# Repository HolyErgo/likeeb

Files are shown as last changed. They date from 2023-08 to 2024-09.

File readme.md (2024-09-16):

# LIKEeb

### 36-key split wireless keyboard
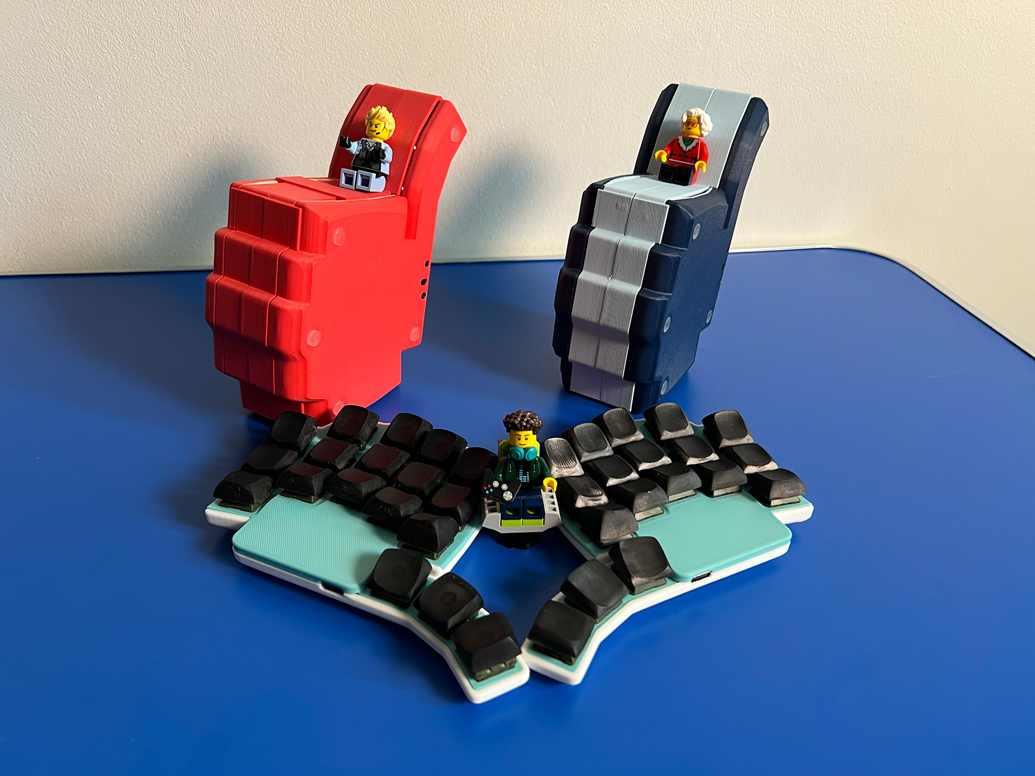
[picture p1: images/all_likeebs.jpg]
Colored likeebs


## Features
- 3x5 key matrix + 3 thumb keys
- highly staggered columns
- rotated pinky and ring columns
- dactyl-like curved columns (not rows)
- Xiao BLE wireless controllers
- hotswap Gateron and Choc V2 switches
- 400mAh battery lasts month or more
- integrated 50-mm magnetic ring
- 2-color case
- magnetic spacer
- no RGB, ergonomics only
- [height-adapted DES-profile keycaps](https://github.com/HolyErgo/DES-MX-low-profile)
- [ZMK firmware](https://github.com/HolyErgo/zmk-likeeb)

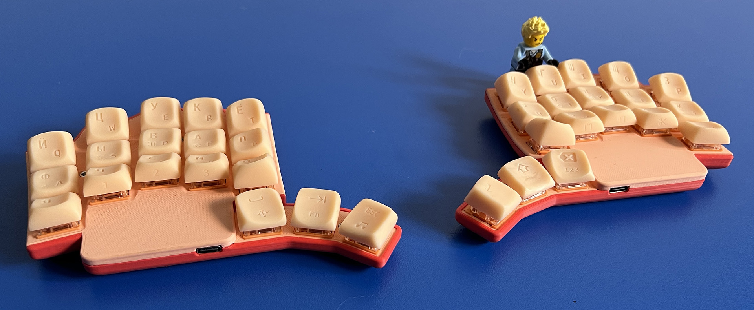
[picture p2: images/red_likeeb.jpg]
Red and biege likeeb

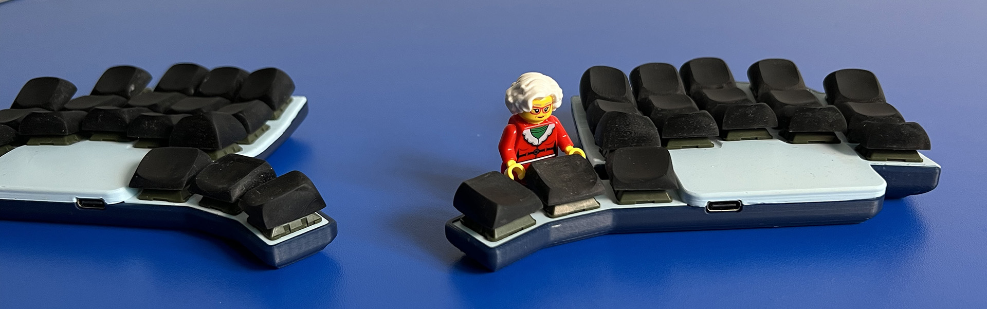
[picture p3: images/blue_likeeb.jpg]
Navy and blue likeeb

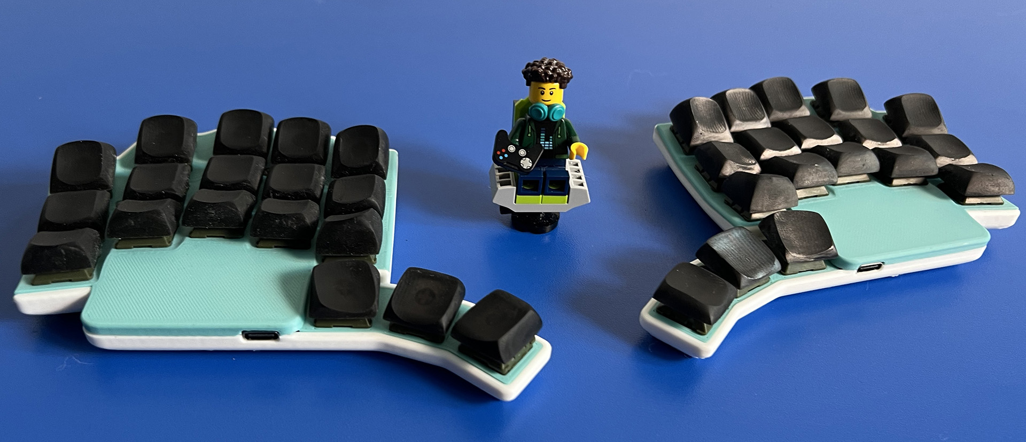
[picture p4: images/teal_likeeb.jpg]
White and teal likeeb


## Comfort and Ergonomics

The curve, stagger, and rotation of the columns provide maximum ergonomics. All keys are easily pressed without moving the base of the hand (for M-L hand size).

Thanks to the low profile, the keyboard is comfortable to use without wrist rests and tents.

Placing the controller under the palm allows for convenient keyboard positioning on either side of a laptop, even on a small café table.

400mAh battery lasts more than a month. I haven’t been able to measure exactly how long, because I always forget when I last charged it :) With the new ZMK firmware using Bluetooth Low Energy protocol, one charge might last 3-4 months.

## Integrated Magnetic Ring

It’s very convenient for designing various mounts. You only need to attach a 0.6mm thick metal ring to the mount. Compared to a magnetic mount, this ring is very thin and much cheaper.

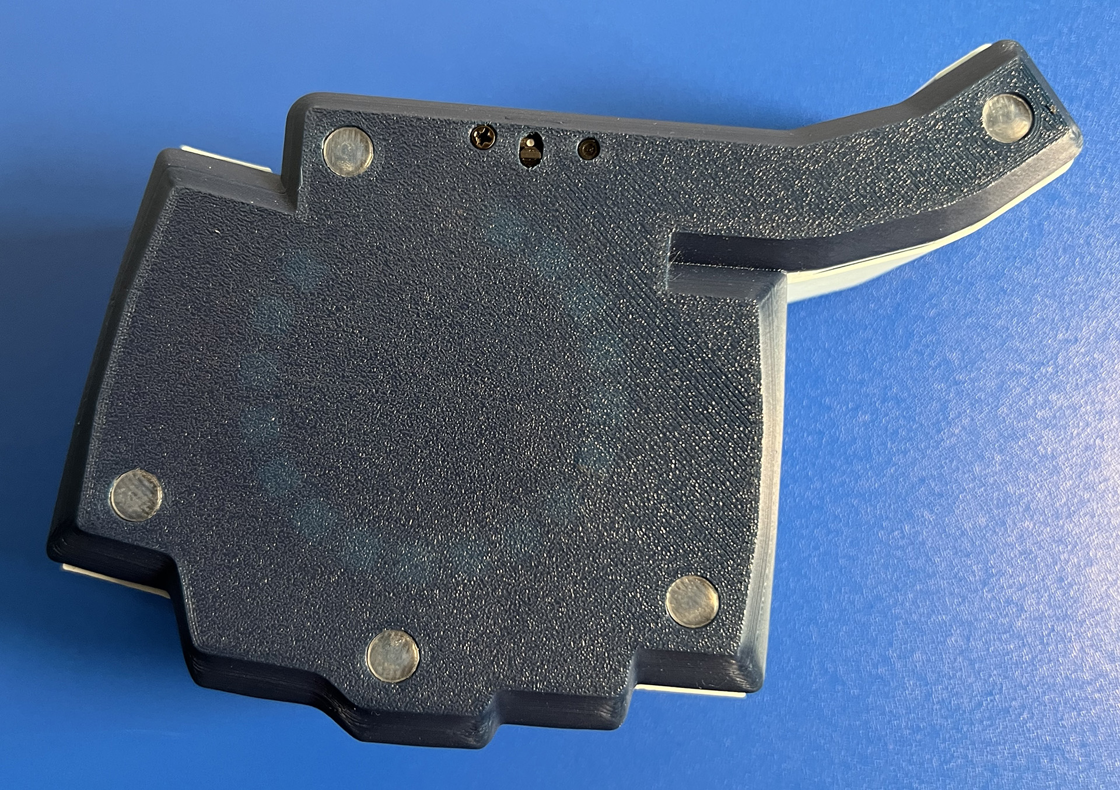
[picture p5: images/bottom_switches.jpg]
Bottom magnet ring and switches


For example, I made a mount for an IKEA garden chair that is only 2mm thick. I simply attached it to the armrest of the chair and created a comfortable workspace: [IKEA chair holder.stl](./case/rev2.0/IKEA%20chair%20holder.stl)

## Convenient Transportation

The magnetic spacer connects two halves of the keyboard and protects the keys from accidental presses. I don’t even turn off the keyboard when I put it in my backpack.

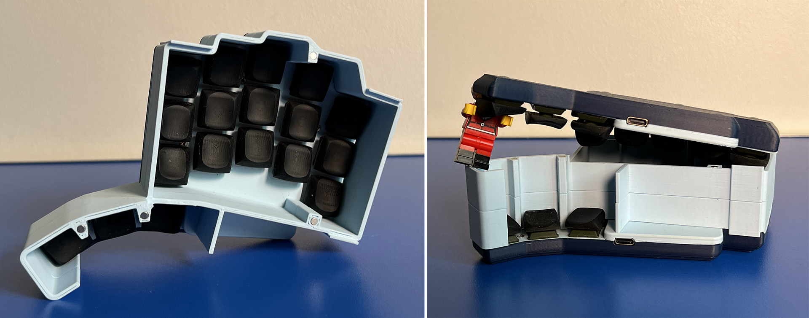
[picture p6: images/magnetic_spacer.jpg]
Magnetic spacer


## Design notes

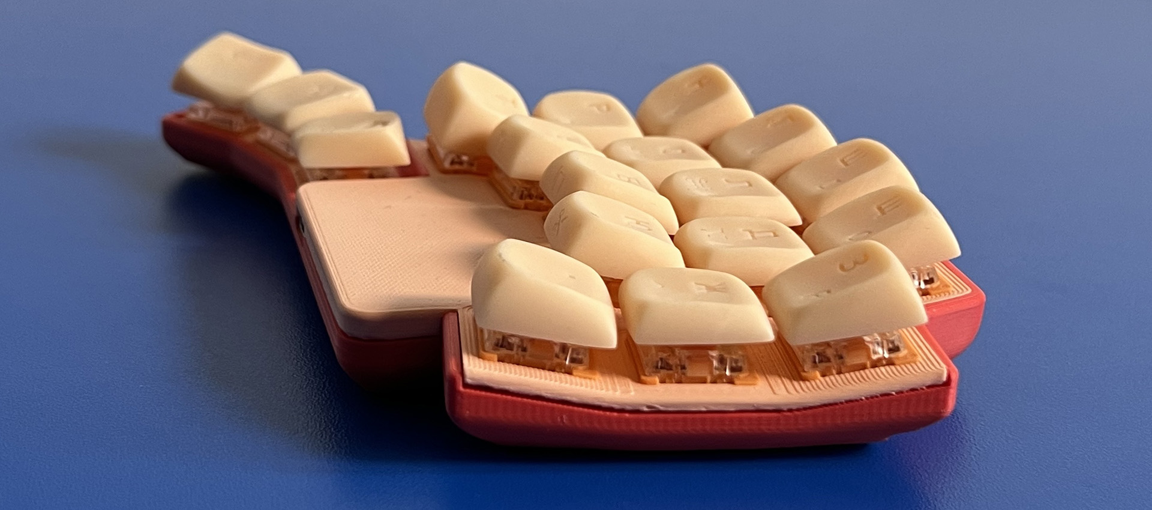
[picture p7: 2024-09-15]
images/curved_columns.jpg

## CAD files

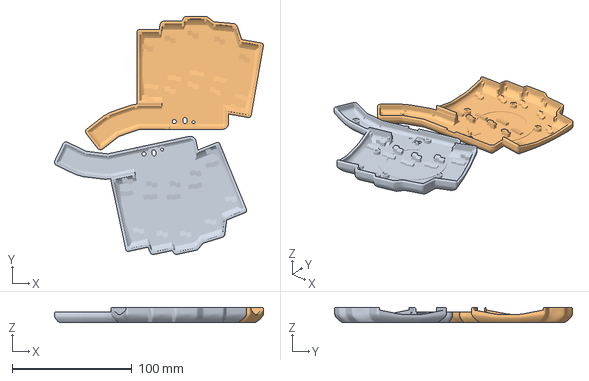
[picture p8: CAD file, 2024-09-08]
case/rev2.0/Bottom.3mf
174.6 x 199.0 x 12.5 mm
bottom l.stl
bottom r.stl

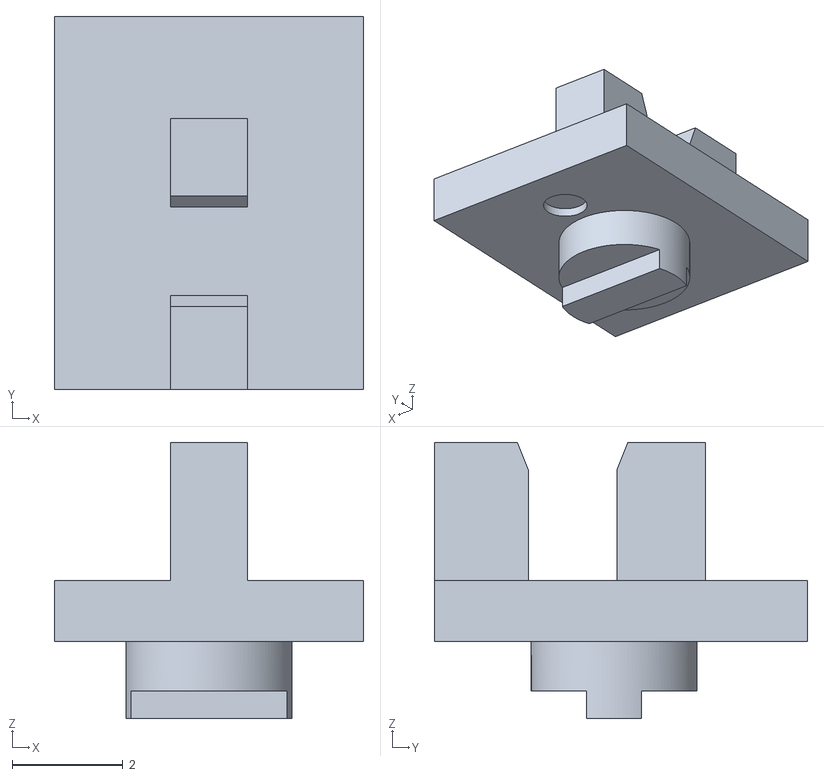
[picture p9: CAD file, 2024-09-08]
case/rev2.0/power stick r.stl
5.60 x 6.75 x 5.00

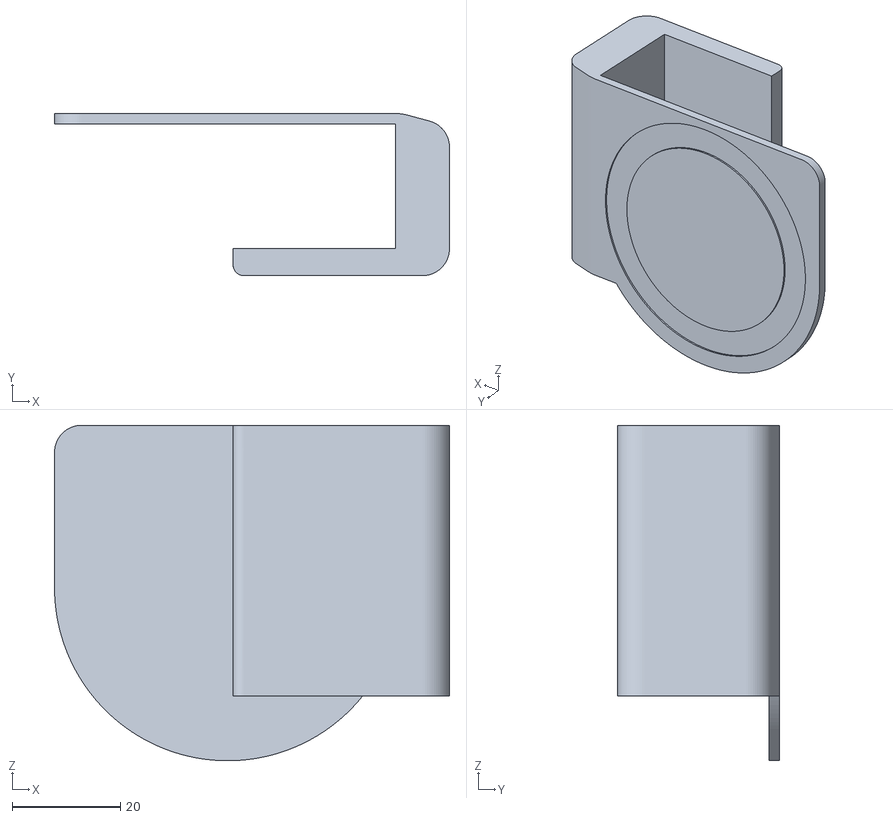
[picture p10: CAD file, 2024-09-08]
case/rev2.0/IKEA chair holder v3.stl
73.0 x 30.0 x 62.0

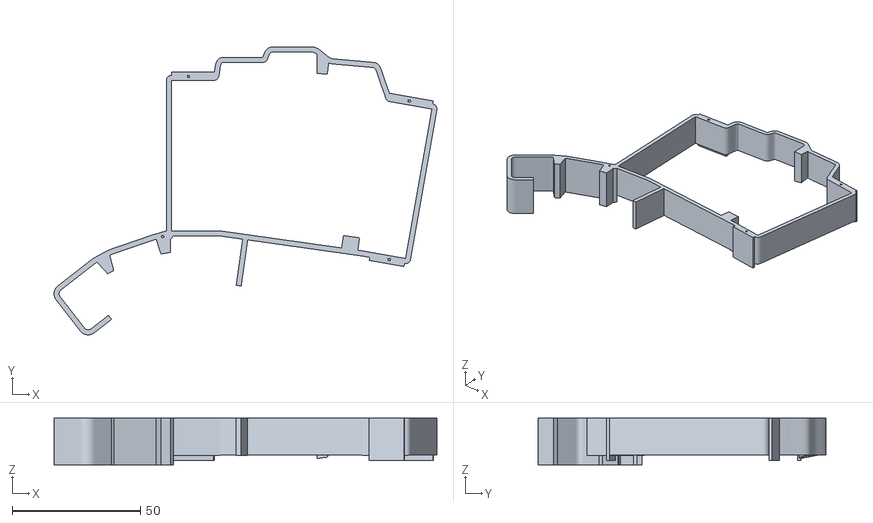
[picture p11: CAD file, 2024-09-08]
case/rev2.0/holder r.stl
149.5 x 112.3 x 18.3

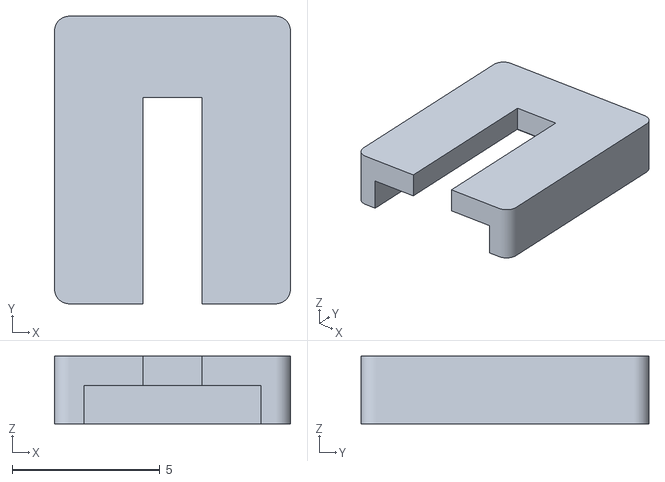
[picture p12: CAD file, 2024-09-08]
case/rev2.0/power holder.stl
8.00 x 9.75 x 2.30

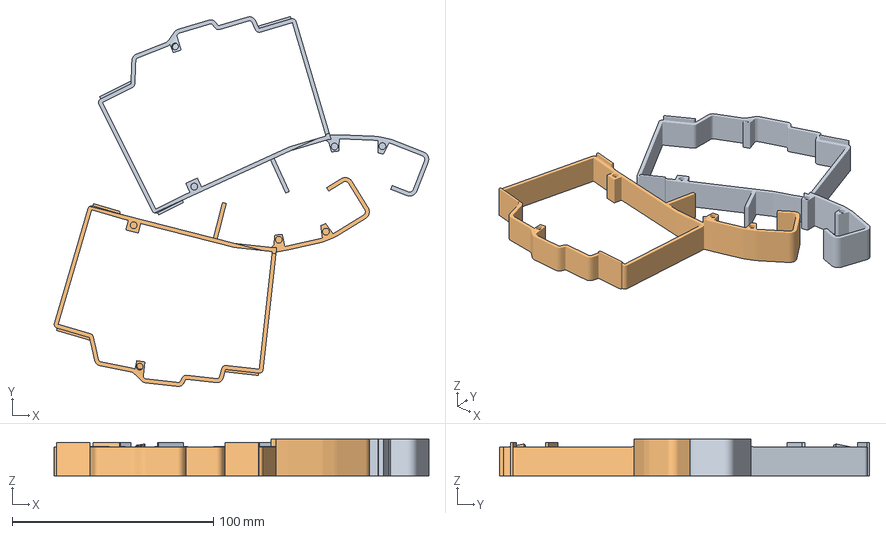
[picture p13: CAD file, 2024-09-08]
case/rev2.0/Holder.3mf
186.1 x 183.8 x 18.3 mm
holder r.stl x 2

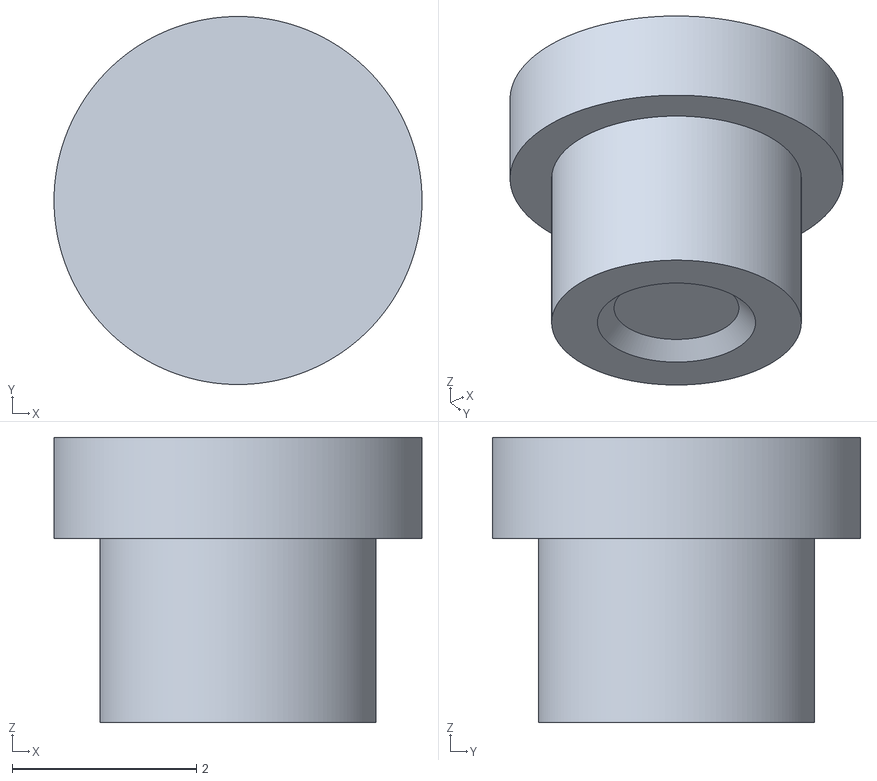
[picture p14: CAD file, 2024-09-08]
case/rev2.0/reset button.stl
4.00 x 4.00 x 3.10

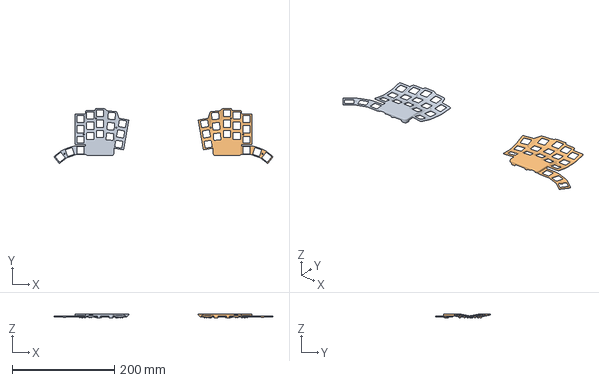
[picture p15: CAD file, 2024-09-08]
case/rev2.0/Top.3mf
428.7 x 107.4 x 7.73 mm
top r.stl
top l.stl

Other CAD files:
case/rev2.0/power stick l.stl

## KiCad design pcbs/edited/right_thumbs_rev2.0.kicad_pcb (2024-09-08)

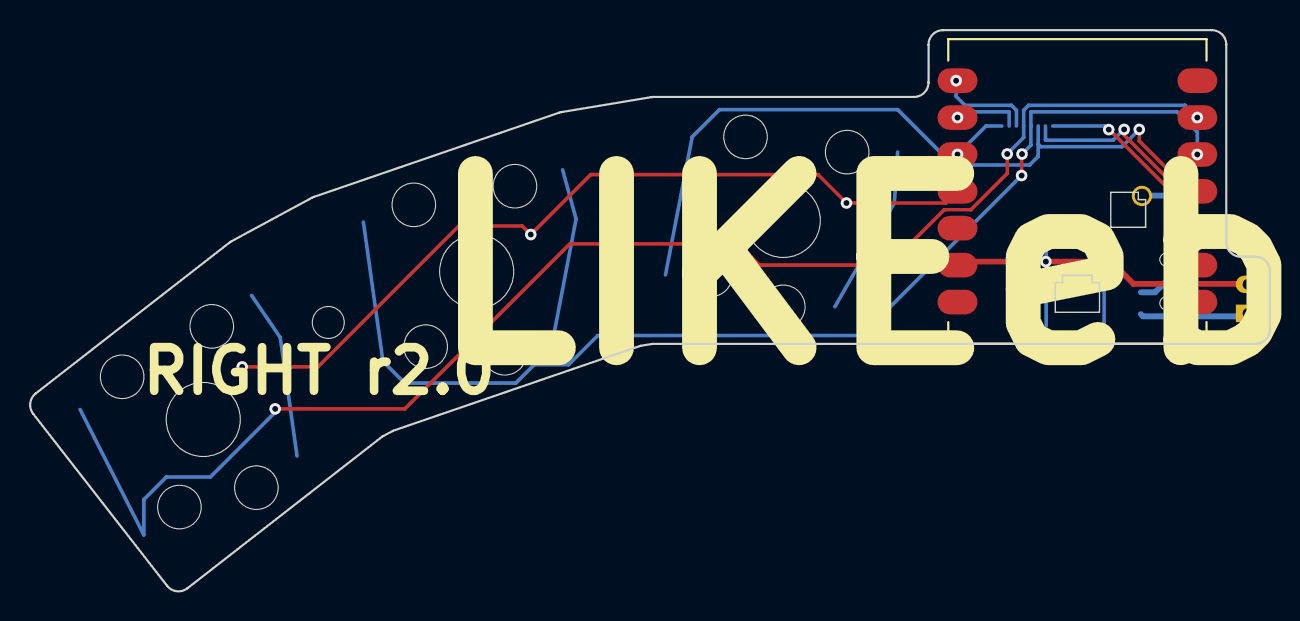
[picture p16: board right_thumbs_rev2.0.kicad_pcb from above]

Board: 2 copper layers, 85.4 x 38.6 mm, 8 parts (1 on the bottom side), 12 nets.

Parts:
B1: SW_TACT_ALPS_SKQGABE010
BAT1: BatteryPad
S1, S2, S3: KS33PG1353
_1: Seeeduino XIAO nRF52840
_2: HKW FPC Socket
_3: MountingHole_2.2mm_M2_Pad_Via

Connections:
C6: S3.1, S3.2, _1.6, _2.4
C7: S2.1, S2.2, _1.5, _2.5
C8: S1.1, S1.2, _1.4, _2.6
C9: _1.3, _2.7
C10: _1.2, _2.8
GND: B1.1, BAT1.2, _1.13
R1: _1.8, _2.3
R2: _1.9, _2.2
R3: _1.10, _2.1
S1_s2d: S1.1, S1.2
S2_s2d: S2.1, S2.2
S3_s2d: S3.1, S3.2

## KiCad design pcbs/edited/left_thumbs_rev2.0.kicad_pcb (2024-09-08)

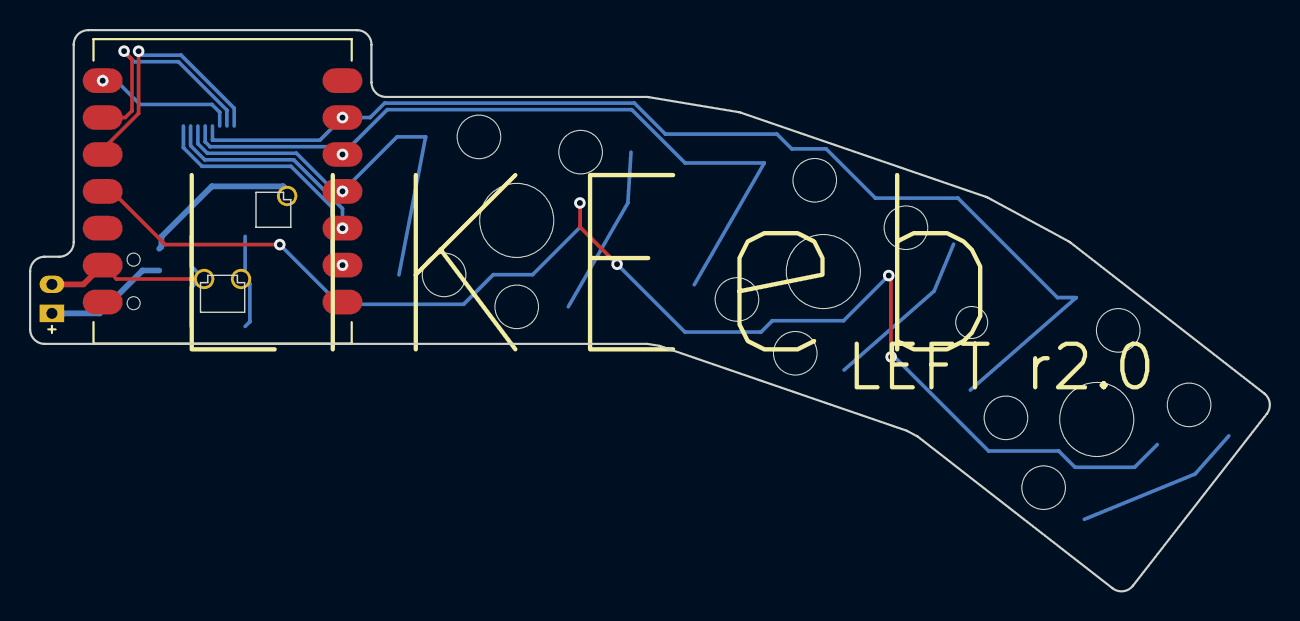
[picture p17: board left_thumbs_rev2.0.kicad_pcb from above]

Board: 2 copper layers, 85.4 x 38.6 mm, 8 parts (1 on the bottom side), 12 nets.

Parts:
B1: SW_TACT_ALPS_SKQGABE010
BAT1: BatteryPad
S1, S2, S3: KS33PG1353
_1: Seeeduino XIAO nRF52840
_2: HKW FPC Socket
_3: MountingHole_2.2mm_M2_Pad_Via

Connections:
C1: _1.2, _2.1
C2: _1.3, _2.2
C3: S1.1, S1.2, _1.4, _2.3
C4: S2.1, S2.2, _1.5, _2.4
C5: S3.1, S3.2, _1.6, _2.5
GND: B1.1, BAT1.2, _1.13
R1: _1.8, _2.6
R2: _1.9, _2.7
R3: _1.10, _2.8
S1_s2d: S1.1, S1.2
S2_s2d: S2.1, S2.2
S3_s2d: S3.1, S3.2

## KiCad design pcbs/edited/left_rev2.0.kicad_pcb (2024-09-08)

Board: 2 copper layers, 16 parts (1 on the bottom side), 20 nets.

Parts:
S1, S2, S3, S4, S5, S6, S7, S8, S9, S10, S11, S12, S13, S14, S15: KS33PG1353
_1: HKW FPC Socket

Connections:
C1: S1.1, S1.2, S2.1, S2.2, S3.1, S3.2, _1.8
C2: S4.1, S4.2, S5.1, S5.2, S6.1, S6.2, _1.7
C3: S7.1, S7.2, S8.1, S8.2, S9.1, S9.2, _1.6
C4: S10.1, S10.2, S11.1, S11.2, S15.1, S15.2, _1.5
C4_R2: S15.1, S15.2
C5: S12.1, S12.2, S13.1, S13.2, S14.1, S14.2, _1.4
S1_s2d: S1.1, S1.2
S2_s2d: S2.1, S2.2
S3_s2d: S3.1, S3.2
S4_s2d: S4.1, S4.2
S5_s2d: S5.1, S5.2
S6_s2d: S6.1, S6.2
S7_s2d: S7.1, S7.2
S8_s2d: S8.1, S8.2
S9_s2d: S9.1, S9.2
S10_s2d: S10.1, S10.2
S11_s2d: S11.1, S11.2
S12_s2d: S12.1, S12.2
S13_s2d: S13.1, S13.2
S14_s2d: S14.1, S14.2

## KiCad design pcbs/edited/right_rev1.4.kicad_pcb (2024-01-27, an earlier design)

Board: 2 copper layers, 16 parts (1 on the bottom side), 5 nets.

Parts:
S1, S2, S3, S4, S5, S6, S7, S8, S9, S10, S11, S12, S13, S14, S15: PG1353
_1: HKW FPC Socket

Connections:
C6: S13.1, S14.1, S15.1, _1.5
C7: S10.1, S11.1, S12.1, _1.4
C8: S7.1, S8.1, S9.1, _1.3
C9: S4.1, S5.1, S6.1, _1.2
C10: S1.1, S2.1, S3.1, _1.1

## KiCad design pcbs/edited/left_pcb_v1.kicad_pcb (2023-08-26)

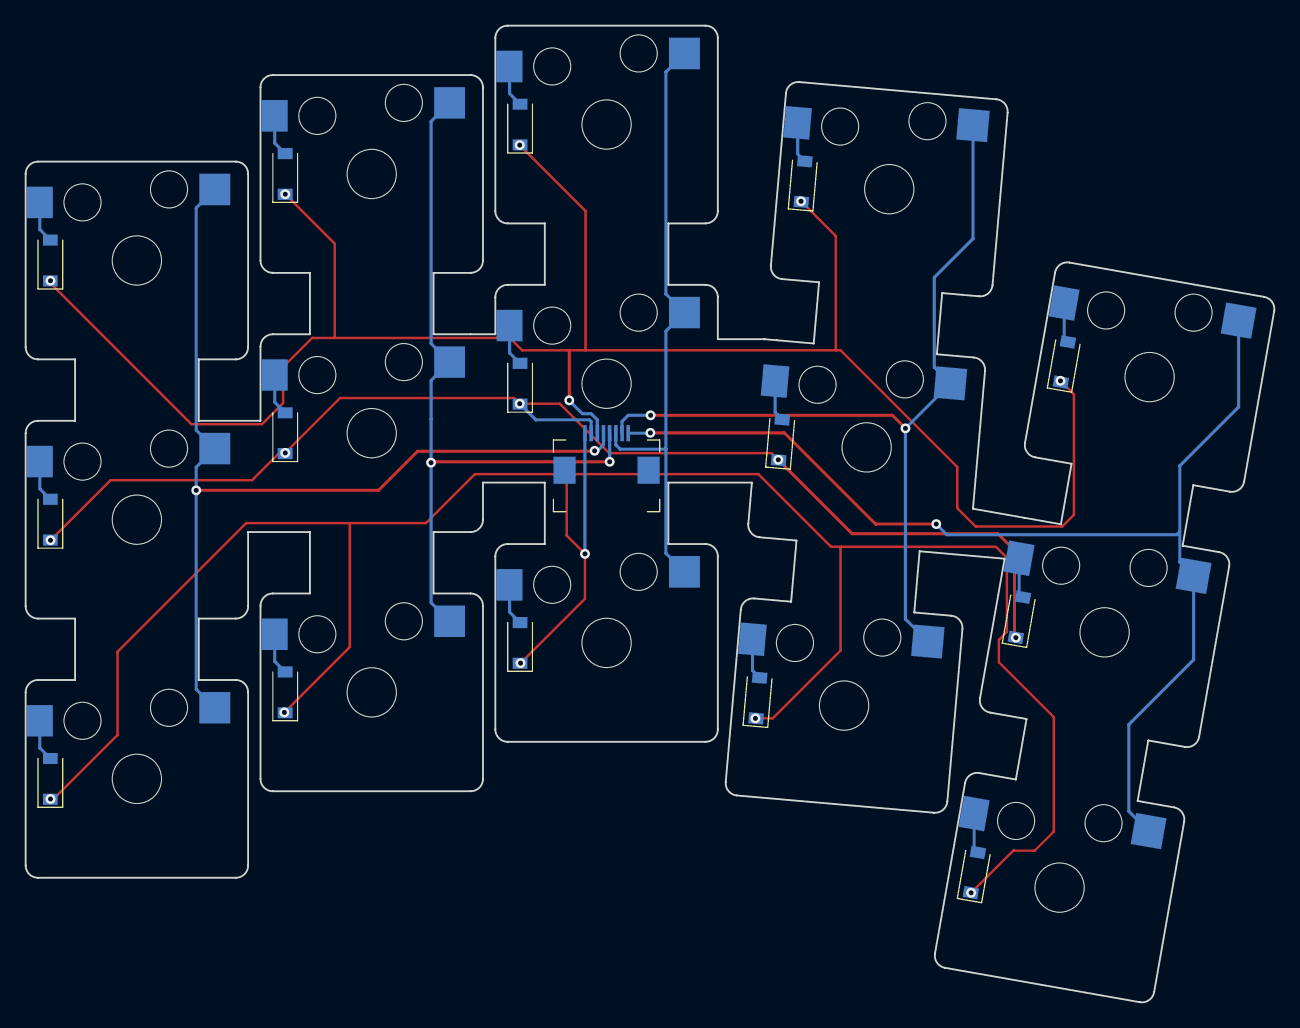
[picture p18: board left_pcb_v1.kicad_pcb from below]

Board: 2 copper layers, 101.0 x 79.0 mm, 31 parts (16 on the bottom side), 23 nets.

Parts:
D1, D2, D3, D4, D5, D6, D7, D8, D9, D10, D11, D12, D13, D14, D15: SmdDiode
S1, S2, S3, S4, S5, S6, S7, S8, S9, S10, S11, S12, S13, S14, S15: MX
_1: HKWClamshellSocket

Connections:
C1: S1.1, S2.1, S3.1, _1.8
C2: S4.1, S5.1, S6.1, _1.7
C3: S7.1, S8.1, S9.1, _1.6
C4: S10.1, S11.1, S12.1, _1.5
C5: S13.1, S14.1, S15.1, _1.4
R1: D2.1, D5.1, D8.1, D11.1, D14.1, _1.3
R2: D1.1, D4.1, D7.1, D10.1, D13.1, _1.2
R3: D3.1, D6.1, D9.1, D12.1, D15.1, _1.1
index_bottom: D12.2, S12.2
index_home: D10.2, S10.2
index_top: D11.2, S11.2
inner_bottom: D15.2, S15.2
inner_home: D13.2, S13.2
inner_top: D14.2, S14.2
middle_bottom: D9.2, S9.2
middle_home: D7.2, S7.2
middle_top: D8.2, S8.2
pinky_bottom: D3.2, S3.2
pinky_home: D1.2, S1.2
pinky_top: D2.2, S2.2
ring_bottom: D6.2, S6.2
ring_home: D4.2, S4.2
ring_top: D5.2, S5.2

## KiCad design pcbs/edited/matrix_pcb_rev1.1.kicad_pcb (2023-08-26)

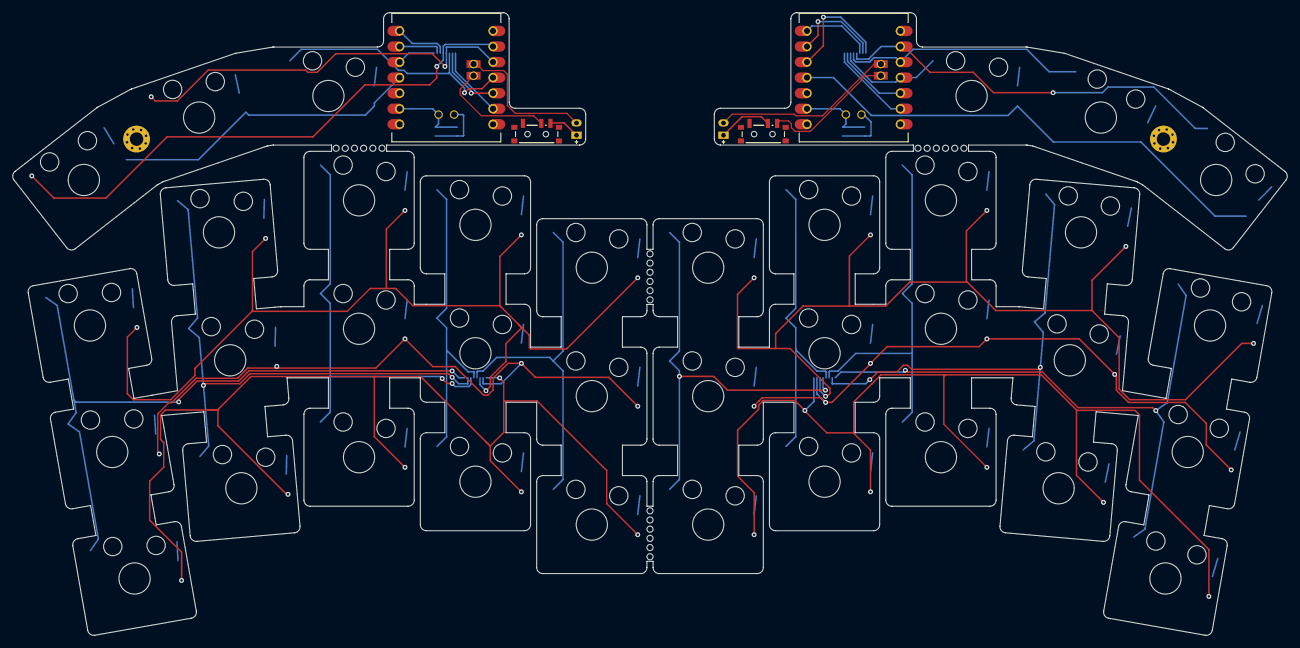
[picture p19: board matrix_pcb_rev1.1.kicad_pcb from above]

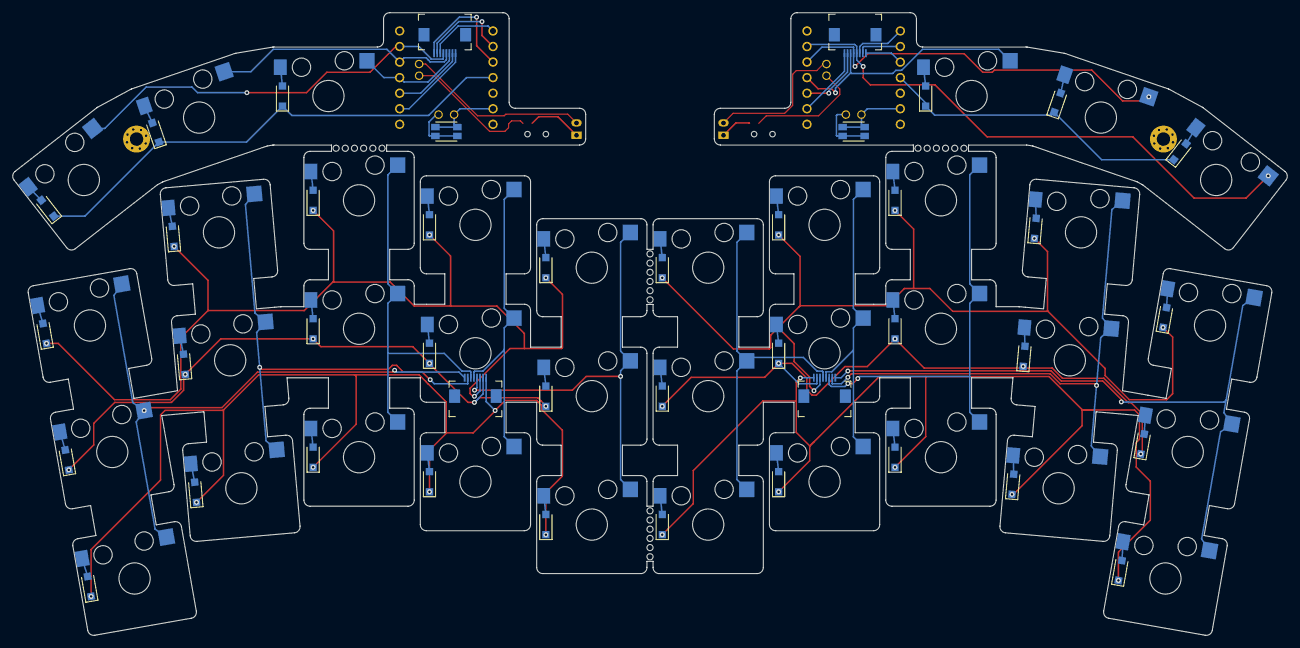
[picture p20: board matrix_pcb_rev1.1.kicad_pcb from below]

Board: 2 copper layers, 208.1 x 101.6 mm, 52 parts (4 on the bottom side), 18 nets.

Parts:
BAT1, BAT2: BatteryPad
S1, S2, S3, S4, S5, S6, S7, S8, S9, S10, S11, S12, S13, S14, S15, S16, S17, S18, S19, S20, S21, S22, S23, S24, S25, S26, S27, S28, S29, S30, S31, S32, S33, S34, S35, S36: GateronLowProfileSwitch
SW1, SW3: power_switch
SW2, SW4: sw_reset_side
_11, _13, _15, _17: HKWClamshellSocket
_14, _18: MountingHole_2.2mm_M2_Pad_Via
_19, _20, _21, _22: Bridge holes 6 x 1mm

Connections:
BAT_P: BAT1.1, SW1.2
C1: S1.1, S2.1, S3.1, _11.8
C2: S4.1, S5.1, S6.1, _11.7
C3: S7.1, S8.1, S9.1, _11.6
C4: S10.1, S11.1, S12.1, _11.5
C5: S13.1, S14.1, S15.1, _11.4
C6: S28.1, S29.1, S30.1, _15.5
C7: S25.1, S26.1, S27.1, _15.4
C8: S22.1, S23.1, S24.1, _15.3
C9: S19.1, S20.1, S21.1, _15.2
C10: S16.1, S17.1, S18.1, _15.1
CT3: S31.1, _13.3
CT4: S32.1, _13.4
CT5: S33.1, _13.5
CT6: S36.1, _17.4
CT7: S35.1, _17.5
CT8: S34.1, _17.6
RBAT_P: BAT2.1, SW3.3

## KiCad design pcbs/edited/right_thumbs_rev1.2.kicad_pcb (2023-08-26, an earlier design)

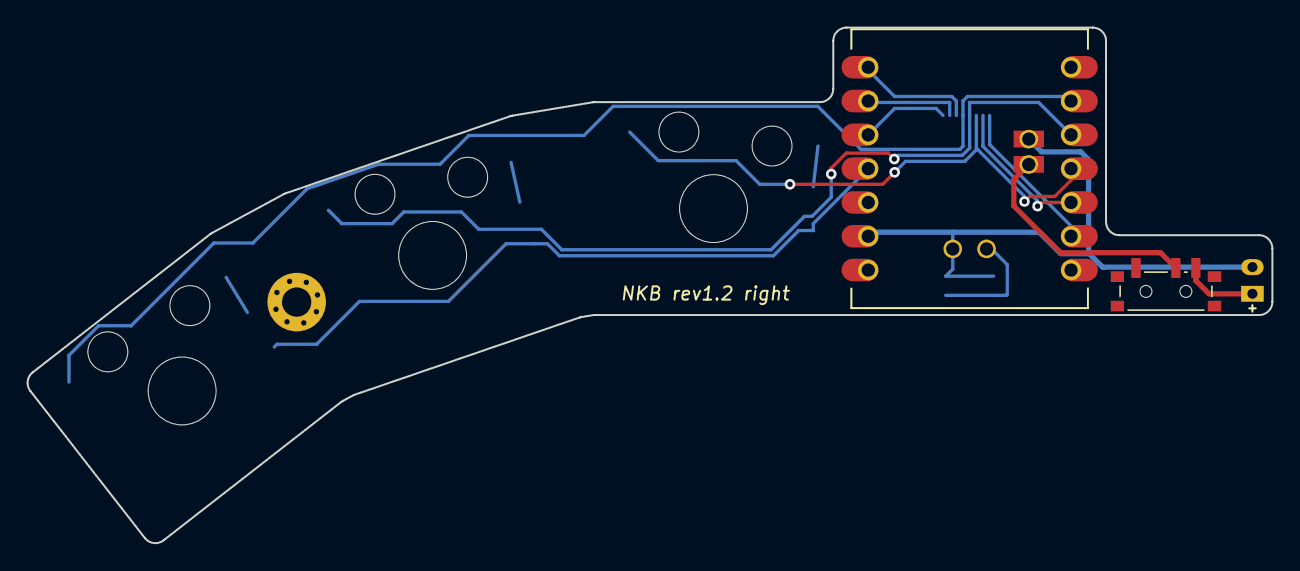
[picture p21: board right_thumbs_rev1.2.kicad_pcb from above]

Board: 2 copper layers, 93.5 x 38.7 mm, 8 parts (1 on the bottom side), 5 nets.

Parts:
BAT1: BatteryPad
S1, S2, S3: GateronLowProfileSwitch
SW1: power_switch
SW2: sw_reset_side
_2: HKWClamshellSocket
_3: MountingHole_2.2mm_M2_Pad_Via

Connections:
CT6: S3.1, _2.4
CT7: S2.1, _2.5
CT8: S1.1, _2.6
RBAT_P: BAT1.1, SW1.3
RGND: BAT1.2, SW2.1

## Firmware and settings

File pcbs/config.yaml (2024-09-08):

meta:
  author: nikservik
  version: rev1.4
units:
  column_stagger: 20.97
  column_connection_width: 2
  sw: 18
  sh: 17
  mcu_width: 23.5
  mcu_height: 21.6
  mcu_x_offset: 1
  xiao_width: 18.5
  xiao_height: 21
  xiao_x_offset: 1
  thumbs_x_offset: 62
  thumbs_y_offset: 49
  pinky_to_ring_spread: 21.556
  pinky_to_ring_stagger: 11.395
  ring_to_middle_spread: 21.411
  ring_to_middle_stagger: 3.297
  diode_set_pitch: 1.8
  socket_x_offset: -2.2
  power_to_reset_offset: 2.5
points:
  zones:
    matrix:
      key.padding: column_stagger
      anchor:
        rotate: 10
        shift: [100, -100]
      mirror:
        ref: matrix_inner_home
        distance: u
      columns:
        pinky:
          key:
            column_net: C1
            mirror.column_net: C10
        ring:
          key:
            splay: -5
            stagger: pinky_to_ring_stagger
            spread: pinky_to_ring_spread
            column_net: C2
            mirror.column_net: C9
        middle:
          key:
            splay: -5
            stagger: ring_to_middle_stagger
            spread: ring_to_middle_spread
            column_net: C3
            mirror.column_net: C8
        index:
          key:
            stagger: -4
            spread: u
            column_net: C4
            mirror.column_net: C7
        inner:
          key:
            stagger: -7
            spread: u
            column_net: C5
            mirror.column_net: C6
      rows:
        home:
          row_net: R2
          mirror.row_net: R2
        top:
          row_net: R1
          mirror.row_net: R1
        bottom:
          row_net: R3
          mirror.row_net: R3
          adjust.shift: [0, -3column_stagger]
    thumbs:
      mirror:
        ref: thumbs_near_only
        distance: -2 thumbs_x_offset + u
      anchor:
        ref: matrix_inner_home
        shift: [thumbs_x_offset, thumbs_y_offset]
      columns:
        near:
          key:
            column_net: C3
            mirror.column_net: C8
        home:
          key:
            spread: 21.11
            stagger: -3.52
            splay: -18.952
            column_net: C4
            mirror.column_net: C7
        far:
          key:
            spread: 21.11
            stagger: -3.52
            splay: -18.952
            column_net: C5
            mirror.column_net: C6
      rows:
        only:
          row_net: R4
outlines:
  left_matrix:
    keys:
      what: rectangle
      where: 
        - /^matrix_.*/
      size: [sw, sh]
      corner: 1
    column_connections:
      what: rectangle
      where:
        - /^matrix_.*_home/
      size: [column_connection_width, 2column_stagger]      
    pinky_to_ring:
      what: rectangle
      where:
        ref: matrix_pinky_home
        shift: [sw/2, sh/2 - 1.5]
      size: [8, 3]
    ring_to_pinky:
      what: rectangle
      where:
        ref: matrix_ring_home
        shift: [-sw/2, -sh/2 + 1.5]
      size: [8, 3]
    ring_to_middle:
      what: rectangle
      where:
        ref: matrix_ring_home
        shift: [sw/2 - 0.5 , sh/2 - 0.5]
      size: [1, 1]
    middle_to_ring:
      what: rectangle
      where:
        ref: matrix_middle_home
        shift: [-sw/2, -2.198]
      size: [(column_stagger + sh/2) * 0.178 + ring_to_middle_spread - u, sh - 4.396]
    middle_to_index:
      what: rectangle
      where:
        ref: matrix_middle_home
        shift: [sw/2, -2]
      size: [4, sh - 4]
    index_to_inner:
      what: rectangle
      where:
        ref: matrix_index_home
        shift: [sw/2, -3.5]
      size: [4, sh - 7]
  right_matrix:
    keys:
      what: rectangle
      where: 
        - /mirror_matrix_.*/
      size: [sw, sh]
      corner: 1
    column_connections:
      what: rectangle
      where:
        - /mirror_matrix_.*_home/
      size: [column_connection_width, 2column_stagger]      
    mirror_pinky_to_ring:
      what: rectangle
      where:
        ref: mirror_matrix_pinky_home
        shift: [sw/2, sh/2 - 1.5]
      size: [8, 3]
    mirror_ring_to_pinky:
      what: rectangle
      where:
        ref: mirror_matrix_ring_home
        shift: [-sw/2, -sh/2 + 1.5]
      size: [8, 3]
    mirror_ring_to_middle:
      what: rectangle
      where:
        ref: mirror_matrix_ring_home
        shift: [sw/2 - 0.5 , sh/2 - 0.5]
      size: [1, 1]
    mirror_middle_to_ring:
      what: rectangle
      where:
        ref: mirror_matrix_middle_home
        shift: [-sw/2, -2.198]
      size: [(column_stagger + sh/2) * 0.178 + ring_to_middle_spread - u, sh - 4.396]
    mirror_middle_to_index:
      what: rectangle
      where:
        ref: mirror_matrix_middle_home
        shift: [sw/2, -2]
      size: [4, sh - 4]
    mirror_index_to_inner:
      what: rectangle
      where:
        ref: mirror_matrix_index_home
        shift: [sw/2, -3.5]
      size: [4, sh - 7]
  _left_thumbs:
    thumb_keys:
      what: rectangle
      where: 
        - /^thumbs_.*/
      size: [sw, sh]
    mcu:
      what: rectangle
      where:
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

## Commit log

2023-08-26 Revision 1.2 - Socket was moved from middle home to inner home - Vertical column connections became thinner
    [left_rev1.2.kicad_pcb, left_thumbs_rev1.2.kicad_pcb, right_rev1.2.kicad_pcb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]
2023-08-29 Right side with 2mm cols connection
    [right_rev1.2_2mm.kicad_pcb]
2023-08-29 Some routing "art" for left side
    [left_rev1.2.kicad_pcb]
2023-09-01 updated Xiao BLE footprint - added holes and edge cut for NFC underside pads - added edge cut for battery underside pads - added edge cut for RST, CLK and DIO underside pads - side pin holes now are 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
2023-09-01 update to use new Xiao footprint
2023-09-01 refactor footprint's filenames
2023-09-01 fix xiao footprint with correct edge cuts for underside pads
2023-09-01 fix power switch with correct pad's net for backside footprint
2023-09-13 revision 1.3 - 2mm column connections - minimized switch area
    [right_rev1.2_2mm.kicad_pcb]
2023-09-13 revision 1.3 pcbs
    [left_rev1.3.kicad_pcb, left_thumbs_rev1.3.kicad_pcb, right_rev1.3.kicad_pcb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]
2024-01-08 added cover and keymap
    [left_pcb_v1.kicad_pcb, left_rev1.2.kicad_pcb, left_rev1.3.kicad_pcb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]
2024-01-22 diodes group footprint
2024-01-22 mounting hole with optional via
2024-01-22 update thumbs with diode groups, mounting hole without via and moved power and reset switches
2024-01-27 choc V2 footprint
2024-01-27 diode set update with via and smaller width
2024-01-27 pcbs rev1.4 with choc v2
    [left_rev1.4.kicad_pcb, left_thumbs_rev1.4.kicad_pcb, right_rev1.4.kicad_pcb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]
2024-09-08 revision 2.0
    [Bottom.3mf, Holder.3mf, IKEA chair holder v3.stl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]
